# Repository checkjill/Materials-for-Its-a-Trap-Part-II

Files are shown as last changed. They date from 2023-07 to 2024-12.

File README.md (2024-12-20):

# Materials-for-Its-a-Trap-Part-II
Files for 3D printing rotating-arm air sampler components and pdf files from 2023 Plant Health workshop materials

## Author information  
Name: Jill Check  
ORCID: [0000-0001-9232-4579](https://orcid.org/0000-0001-9232-4579)  
Institution: Michigan State University  
Email: checkjil@msu.edu  
 
## Publication information  
Title: It’s a Trap! Part II: An Approachable Guide to Constructing and Using Rotating-Arm Air Samplers  
Journal: Plant Disease  
Authors: Jill C. Check, Rebecca J. Harkness, Lexi Heger, Martin I. Chilvers, Walter F. Mahaffee, Monique L. Sakalidis, and Timothy D. Miles  
doi: 10.1094/PDIS-01-24-0131-SR  

## Contents  
* Basic sampling arms:
  * 1.2mm Basic Sampling arm.stl
  * 1.6mm Basic Sampling arm.stl
* Retracting sampling arm parts:
  * Retracting Arm Parts - Cam.stl
  * Retracting Arm Parts - Holder.stl
* Workshop materials
  * APS Workshop 2023.pdf
  * Materials_workshopPDF.pdf

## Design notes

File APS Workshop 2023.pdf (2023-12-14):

# Capturing the wind a guided session on low-cost airborne

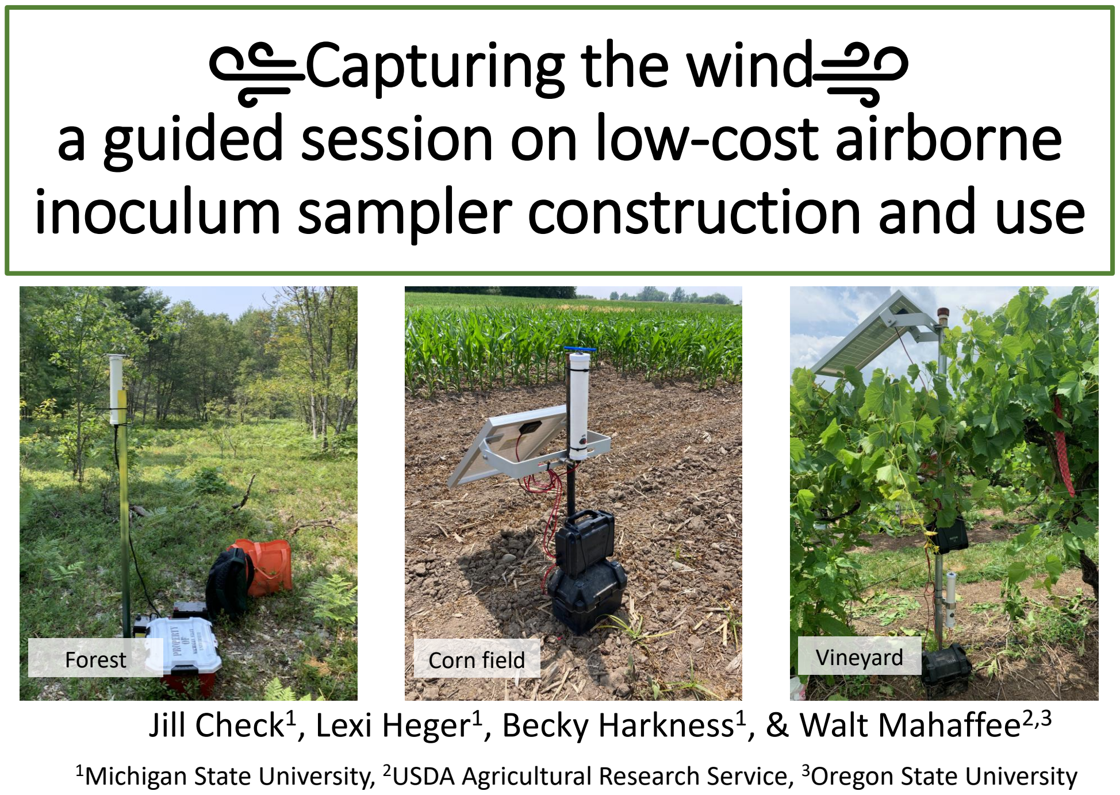
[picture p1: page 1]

# inoculum sampler construction and use

Jill Check¹

, Lexi Heger¹

, Becky Harkness¹

, & Walt Mahaffee²,3

Forest | Corn field | Vineyard

1Michigan State University, ²USDA Agricultural Research Service, ³Oregon State University

# Guided construction

# What’s in the box?

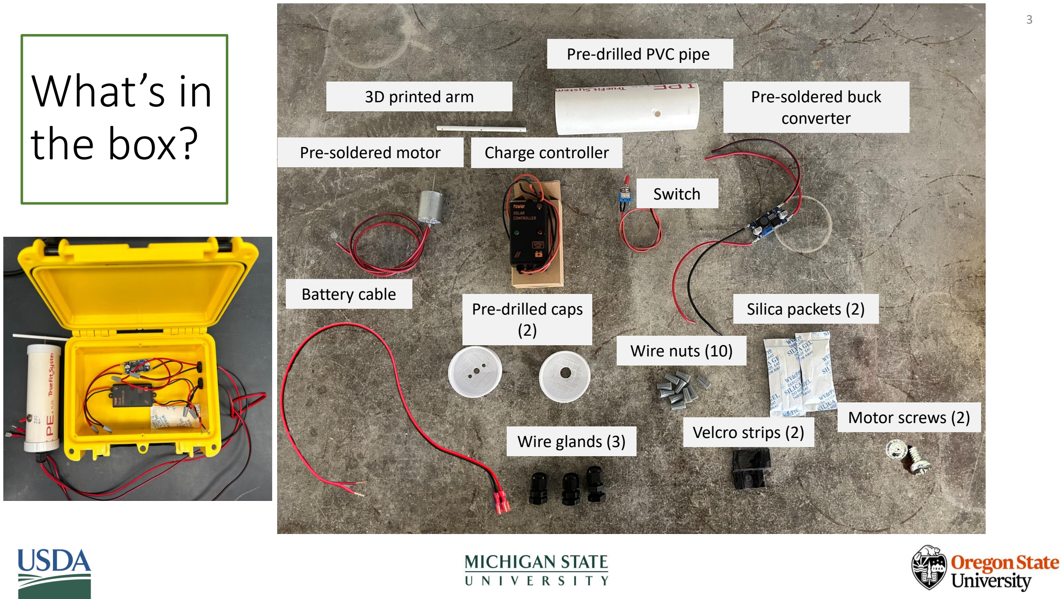
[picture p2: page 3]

Pre-soldered motor

3D printed arm

Pre-drilled PVC pipe

Pre-soldered buck
converter

Charge controller

Switch

Silica packets (2)

Wire nuts (10)

Velcro strips (2)

Pre-drilled caps
(2)

Wire glands (3)

Battery cable

Motor screws (2)

# Mounting the motor (1)

- Test the motor—Touch the wire ends from the soldered motor to a charged
battery (positive to positive and ne gative to negative) to make sure the motor is functional
- Using the screws (2) and a small flat-head screwdriver, secure the motor to the pre-drilled PVC end cap
- Touch the motor wire ends to the battery to check that the screws are not preventing the motor from spinning

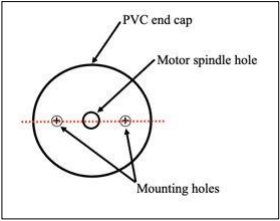
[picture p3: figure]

Diagram of the pre-drilled PVC end cap used for mounting the motor; cap should be flush with the motor

# Mounting the motor into the PVC (2)

- Gently thread the wires from the motor through the PVC pipe
- Snap the PVC end cap with the motor onto the pipe. The motor should be placed at the end of the PVC pipe, opposite where the switch hole was pre-drilled

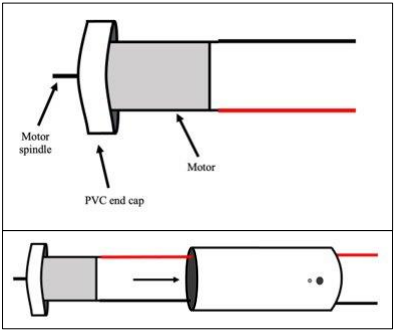
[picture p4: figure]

Top: PVC cap with motor secured and wires soldered Bottom: Placement of motor into PVC pipe casing

# Connecting the power switch (1)

- Cut the positive wire 8 cm (3.15 in) beyond the bottom of the PVC pipe
- Strip the end of the wire. Set aside excess wire for use later
- Using a wire nut, connect the positive wire from the motor to the
positive wire of the switch. Gently tug on each cable used in the connection to make sure it is secure

Diagram of motor inside PVC pipe casing and wire that will be cut (for the switch) after being pulled through the bottom of the PVC pipe.

# Connecting the power switch (2)

- Remove the washer and nut from the switch and set them aside
- Insert the switch through the hole drilled into the PVC pipe

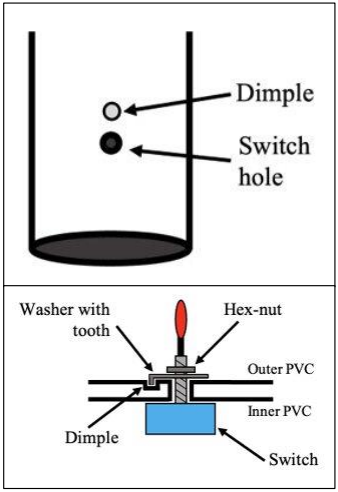
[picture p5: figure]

Top: Diagram of the front of the pre-drilled PVC pipe where the switch will be added. Bottom: Layout of the switch from profile view of the pipe.

# Connecting the power switch (3)

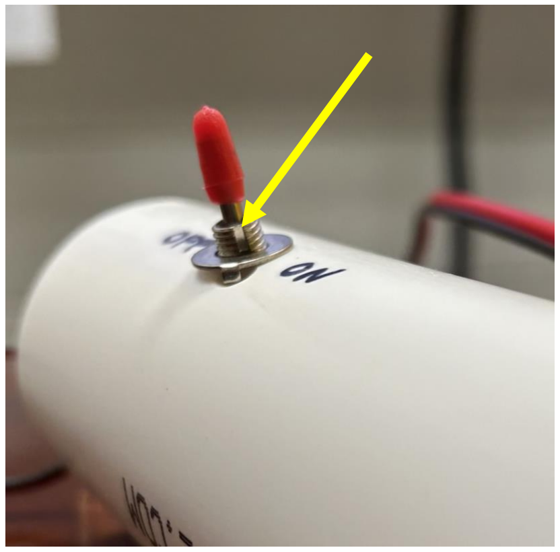
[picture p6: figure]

- While holding the switch from the inside the pipe, seat the washer tooth in the dimple above the switch hole on the PVC pipe
- Screw the small hex-nut on top of the washer
- Use the excess positive wire from the motor and use a wire nut to attach it to the negative wire of the switch

Note: the area around the switch can be sealed with duct seal to prevent water damage

# Finishing the PVC pipe enclosure (1)

- Remove the hex nut from the wire gland and screw the gland into the threaded hole in the bottom PVC end cap; the sealing nut of the wire gland needs to be on the outside (smooth) of the end cap
- Loosen the sealing nut of the wire gland and thread the wires through

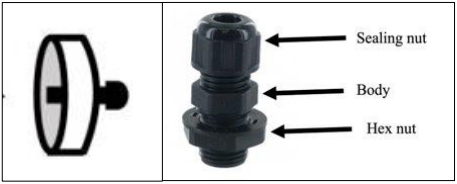
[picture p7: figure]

Orientation of wire gland in the bottom end cap; description of wire gland pieces

# Finishing the PVC pipe enclosure (2)

- Add 1 silica gel pack inside the PVC pipe
- Gently push the wires and wire nuts connecting the switch to the rest of the circuit into the PVC pipe
- Tighten the sealing nut on the wire gland
- Snap the cap onto bottom of the PVC pipe

Note: the end caps should be waterproof using silicone caulk before deploying

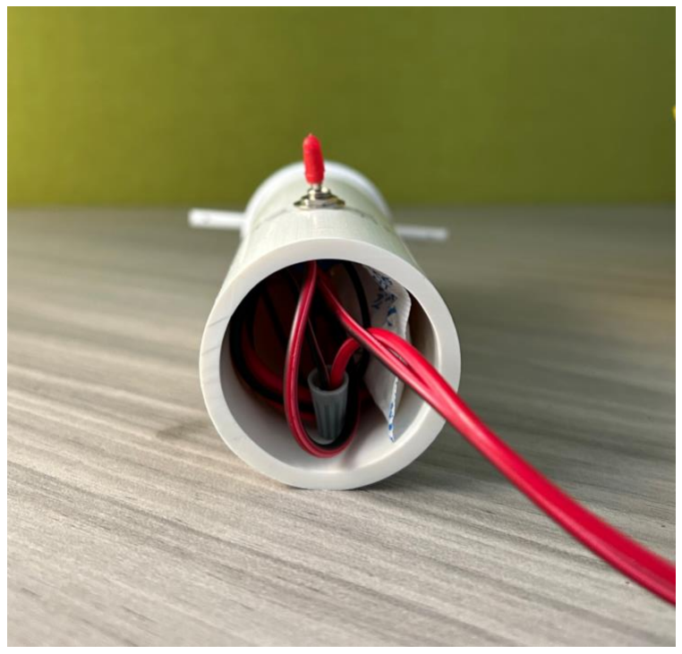
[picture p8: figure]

Inside of PVC pipe at this step; silica gel pack and wires with nuts placed inside the pipe, remaining wires leading out of PVC pipe.

# Finishing the PVC pipe enclosure (3)

- Using the battery, touch the wires that are threaded through the PVC end cap (positive to positive and negative to negative). Ensure the motor and switch are functioning properly.
- Use a sharpie to label on the PVC pipe the ON and OFF switch positions.

Diagram of the motor enclosure PVC pipe with the wire gland-threaded PVC cap

# Circuitry – preparing the enclosure (1)

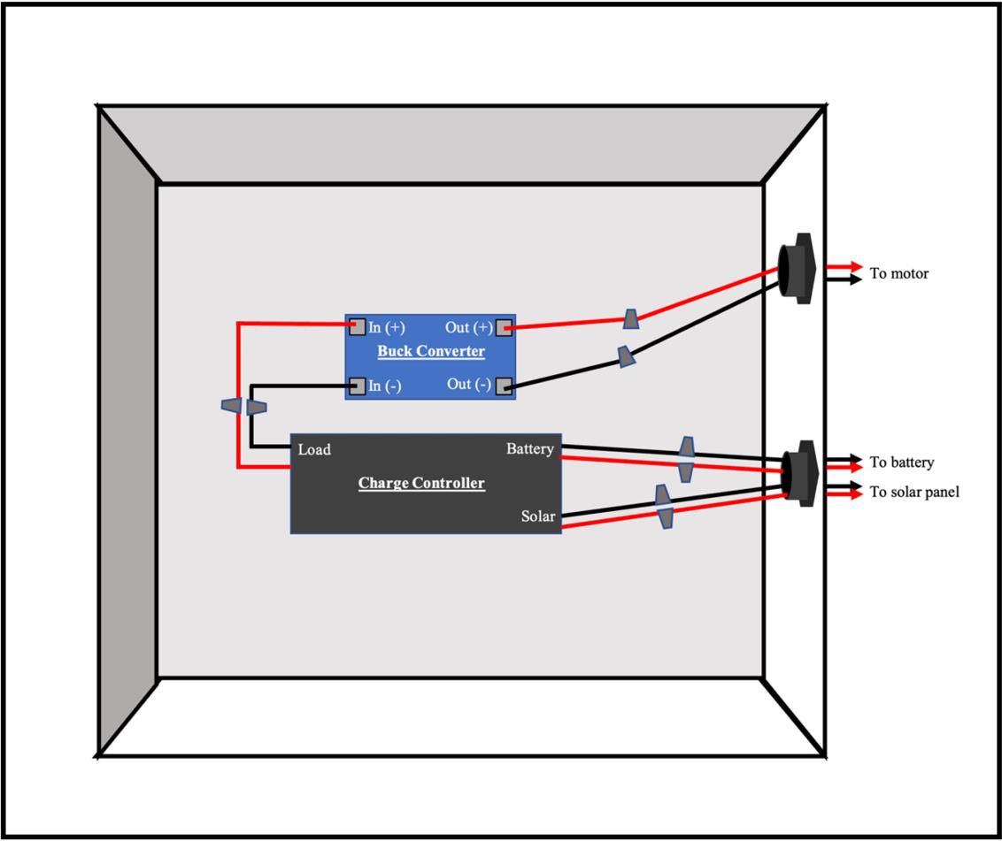
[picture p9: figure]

- Screw a wire gland into each pre-drilled (side) hole of the box with the sealing nut facing out and the hex-nut on the inside
- Loosen the sealing nut and thread the wires from the PVC pipe (motor) through the top wire gland

# Circuitry – preparing the enclosure (2)

- Place the buck converter inside the enclosure with the OUT side oriented towards the wire gland.
- Use Velcro strips to secure the buck converter to the back wall of the enclosure

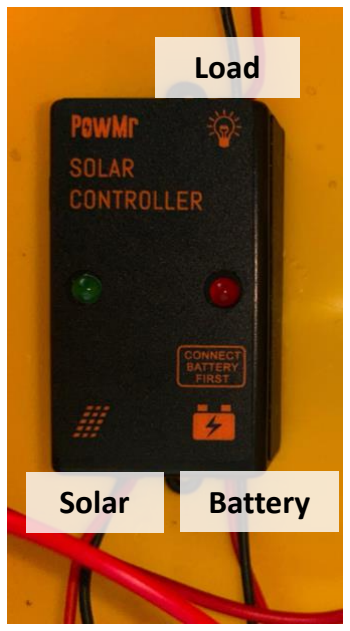
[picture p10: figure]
Solar; Battery; Load

- Place the charge controller inside
the enclosure with the LOAD connections oriented away from the wire glands.
- Use Velcro strips to secure the charge controller to the back wall of the enclosure

# Circuitry – buck convertor

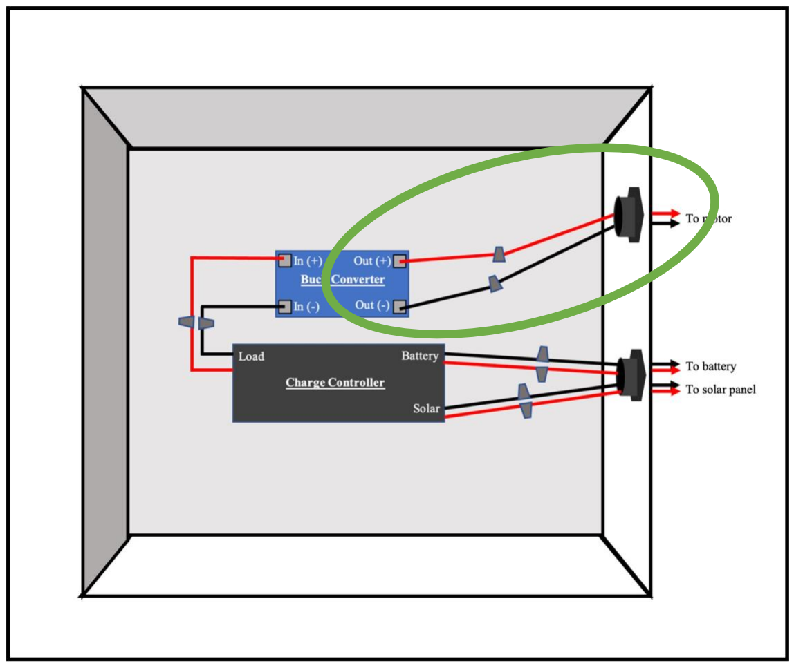
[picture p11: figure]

- Use wire nuts, connect the positive and negative wires coming from the PVC (motor and switch) to the OUT connection site of the buck convertor

# Circuitry - charge controller

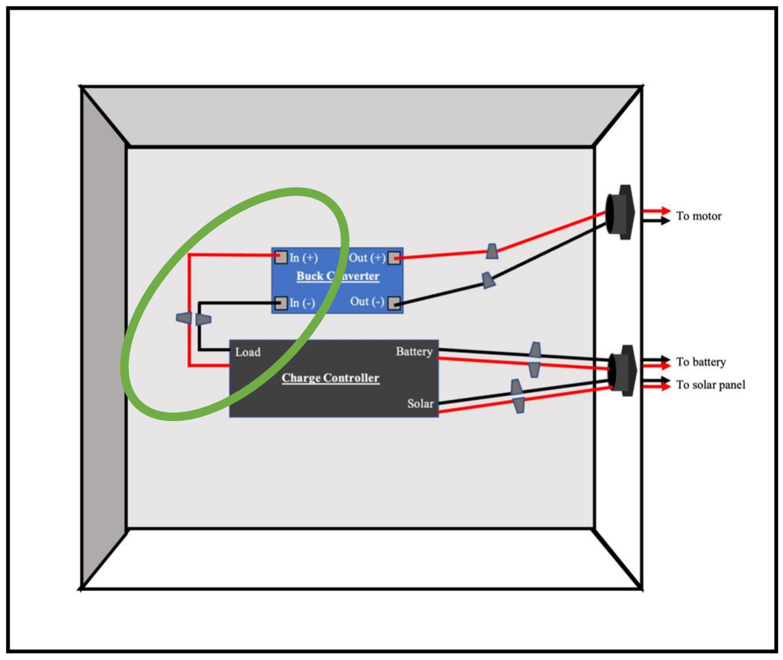
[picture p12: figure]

- Remove the pre-cut insulation of both wires from the LOAD connection sites of the charge controller
- Use wire nuts to connect
the positive and negative wires from the IN connection site of the buck convertor to the LOAD wires from the charge controller
- Take a moment to ensure the buck convertor is wired in the correct orientation: backwards connection to the battery and motor can cause failure when connected to a power source

# Circuitry - battery cable

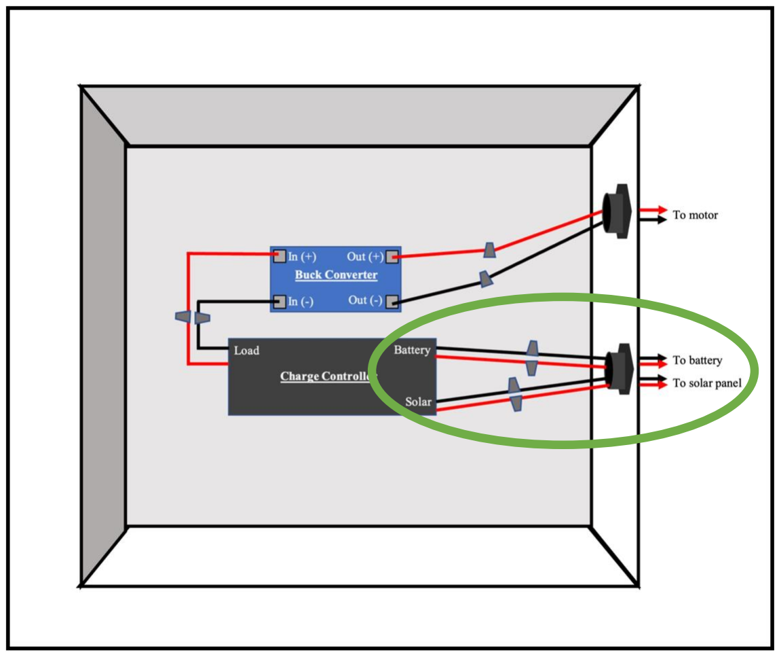
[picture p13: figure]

- Thread the pre-crimped battery cable with spades into the enclosure
with spades outside
- Using wire nuts, connect the positive and negative wires from the BATTERY connection site of the charge controller to the positive and negative wires of the battery cable
- Tighten both wire glands on the outside of the enclosure, making sure there is no tension on the wires and connections within the enclosure

# Circuitry - testing with a battery

- Ensure the switch on the PVC pipe is in the OFF position
- Connect the wire spades to the terminals of the battery
(positive to positive and negative to negative)
- Holding the PVC pipe upright, flip the switch toggle to test the circuitry connections

# Calibrating rotating-arm speed

- Place the rotating-arm onto the motor spindle (apply even pressure)
- While connected to the battery, have a partner hold the PVC pipe and turn ON the motor using the switch
- Use a digital tachometer to measure the spin of the rotating-arm
- Use a small flat head screwdriver to adjust the speed of the motor using the screw on the buck convertor. Recheck the motor speed using the tachometer. Repeat until the desired speed is achieved (try to aim for 4800 RPM)

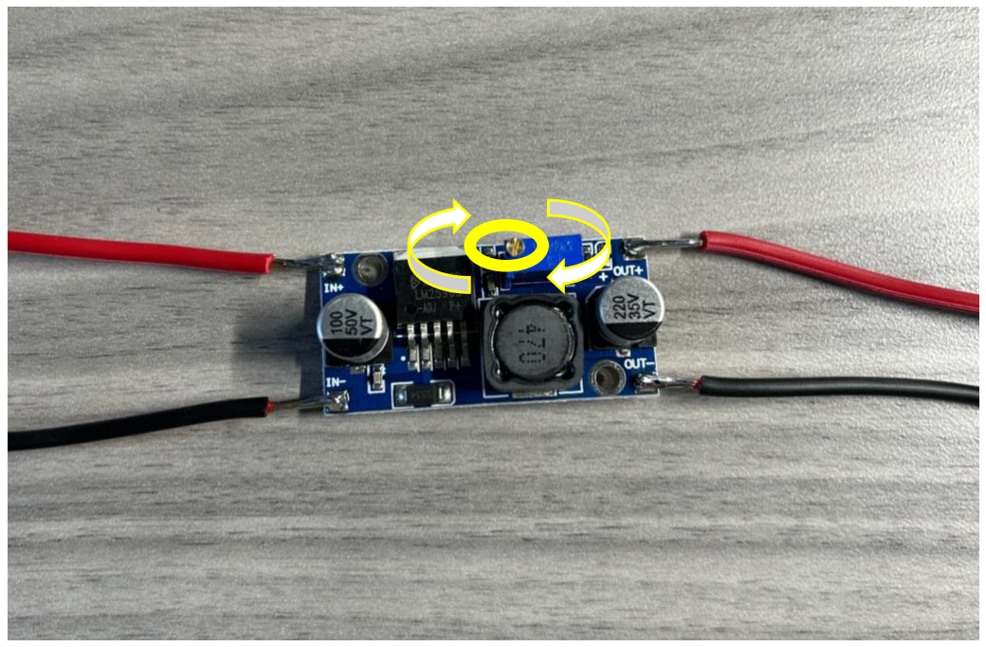
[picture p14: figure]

Clockwise = speed up
Counter = slow down

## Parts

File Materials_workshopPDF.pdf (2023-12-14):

Capturing the wind
a guided session on low-cost airborne inoculum sampler construction and use

Check, Harkness, Heger, & Mahaffee

Item | Quantity per sampler | Notes
Adjustable buck converter | 1 | 12 V, DC-DC required. Serves as a modulator for power from the battery to the motor, can be adjusted to alter speed. Increasing voltage to the motor will increase rotational speed.
Battery | 1 | Charged for testing during building
Charge controller | 1 | 5 A current rating. Some solar panels are sold with control elements preinstalled. Preinstalled controllers are preferable to external ones.
Hook and loop fastener | 2 | 25.4 mm (1 in) width; used to mount the buck converter and charge controller to the box.
Insulated wire terminals | 2 | Should match gauge of wire and shape of battery terminals
Motor | | Direct current (DC) 12 V motor recommended.
Schedule 40 PVC | 1 at 15 cm (6 in) | For motor encasing, wire, and switch mounting. Alternatively, switch may be mounted within controls box. Size varies.
Schedule 40, 38 mm (1.5 in) PVC end cap (test cap) | 2 | Must be flat-top, not convex. One for the top and bottom of the sampler, or the top and bottom of the PVC pipe (above)
Screws to mount motor | 2 | Size will depend on the motor and PVC thickness. If screws are too long, the motor may fail or break. Testing different screw lengths is recommended (author experience suggests 3mm (M3) based on materials in this guide)
Silica gel pack | 2 | One into controls box and one into PVC pipe to maintain dryness
Switch (2 pin toggle) | 1 | Rated for at least 5 A and 6 V or 12 V.

8/12/23

Capturing the wind
a guided session on low-cost airborne inoculum sampler construction and use

Check, Harkness, Heger, & Mahaffee

Item | Quantity per sampler | Notes
Waterproof enclosure | 1 | Ideally it will be 2 mm (0.1 in) in wall thickness. If plastic is too thin there will not be enough threads in tapped holes for proper waterproofing.
Wire | 3 m (9.8 ft) broken into increments | Dependent on sampler height and modifications. 18 gauge (AWG) recommended. Should have UV-stable casing if being used for multiple seasons. Always err on the side of caution and purchase extra wire.
Wire glands | 3 | Must match tap size and fit chosen wire gauge (11.5 mm (29/64 in) recommended for most applications).
Wire nuts | 10 | Base size off chosen wire gauge; number dependent on sampler design
3D printed arm | 1 | Parameters and materials subjective; can be designed using online tools and then printed at a university, public library, or private company. Today’s material is PTG (Polyethylene Terephthalate Glycol) printing filament (thermal resistance and high strength)

### Tools for building (at the workshop)

Flat head screwdriver (small; 2.5mm) | 1 | For securing screws to motor and altering control of buck converter
Multimeter | 1 | Auto-ranging is recommended; used to troubleshoot and read voltage
Permanent marker | 1 | For marking various pieces
Tachometer | 1 | Digital laser; for measuring rotating-arm speed; speed is calculated by dividing final read number in half.
Wire crimper/stripper | 1 | Recommended using with a spring (and 18 gauge wire capability)

8/12/23

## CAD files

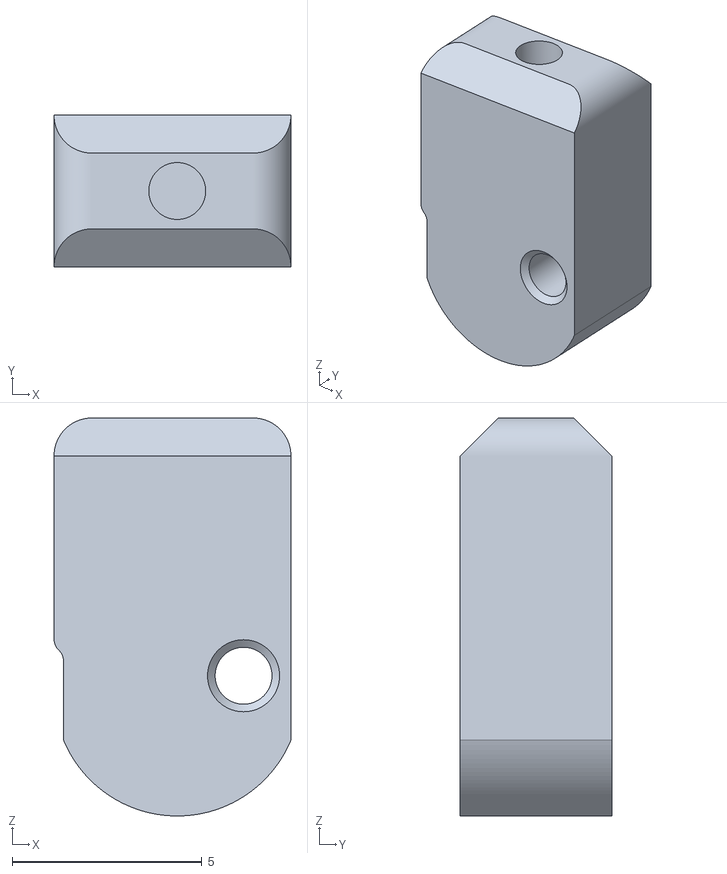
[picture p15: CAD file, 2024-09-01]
Retracting Arm Parts - Cam.stl
6.25 x 4.00 x 10.5

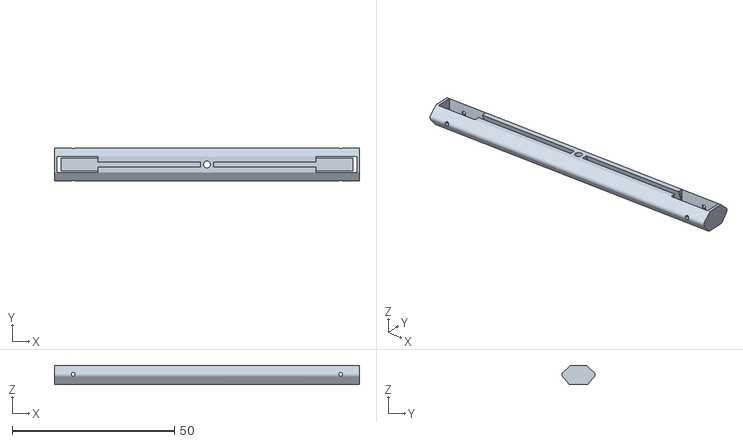
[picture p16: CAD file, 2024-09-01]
Retracting Arm Parts - Holder.stl
94.1 x 10.2 x 6.00

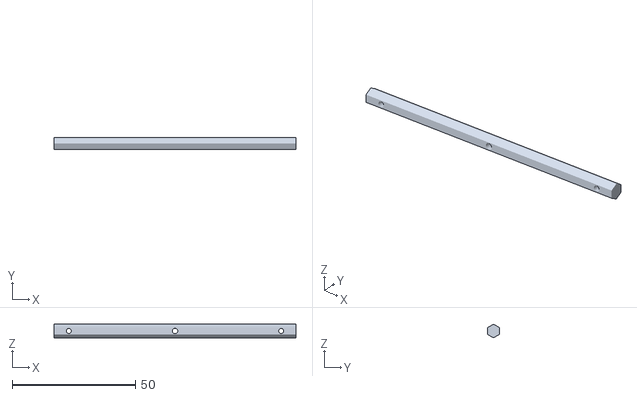
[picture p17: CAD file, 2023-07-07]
1.6mm Basic Sampling Arm.stl
98.0 x 4.82 x 5.54

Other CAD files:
1.2mm Basic Sampling arm.stl
